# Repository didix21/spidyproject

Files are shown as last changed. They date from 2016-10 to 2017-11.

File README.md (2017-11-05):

# spidyproject


HitCount (http://hits.dwyl.io/didix21/spidyproject)
## About it
This repository contains all the necessary firmware to be implimented in Arduino's Spidy. Spidy is a six leg robot which is controlled with an Arduino and the spidyfirmware.  
Based on the robot: [Funny six feet + Myo](http://www.thingiverse.com/thing:1201161/#files)

# Characteristics
Description about the hardware and firmware used in spidy.
## Hardware
 * Plastic chasis.
 * Arduino.
 * 16 channels pwm controller.
 * 13 servo motors SG90.
 * Ultrasonic sensor.
 * MPU-6050 3 Axis Acceleration + Gyroscope / 6 Axis Attitude Module.
 * Raspberry Pi 2.0. (Optional for controll it manually)
 
 ## Firmware
 * spidyfirmware

## Things to do
**Hardware**
  * Implement the 16 channels pwm controller.
  
**Software**
  * Create new code for using the previous hardware.

## Contributors

- [Sxubach](https://github.com/sxubach)
  - He will create the communication between a PC, the Raspberry Pi 3.0 and Arduino MEGA. 

- [didix21](https://github.com/didix21)
  - Build the robot and the Hardware and implement it with a firmware that will allow to control the servos, obtain IMU's and Ultrasonics sensor data.

- [XMabbX](https://github.com/XMabbX)
  - Investigate about the algorithm which will allow the robot to learn to walk and prepare for the next step of the project.

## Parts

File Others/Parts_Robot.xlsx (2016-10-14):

Parts | Nº of them needed | Nº of Screws | Metrics | Length | Parts joined
LegP_0 | 6 | 2 | M3 | 15 mm M3 | LegP_1, LegP_2
LegP_1 | 6 | 2 | M3 | 15 mm M3 | LegP_0, LegP_4
LegP_2 | 6 | 1 | M3 | 15 mm M3 | LegP_0
LegP_3 | 13 | 1 | M3 | 8 mm M3 | 1xLegP_4, 1xLegP_5, 1xUSSensorFrame
LegP_4 | 6 | 4 | M3 | 3x 8 mm M3, 1x 15 mm M3 | LegP_1, LegP_3, LegP_5
LegP_5 | 6 | 3 | M3 | 3x 8 mm M3 | LegP_3, LegP_4
Base6servo | 1 | 4 | M3 | 4x 4 mm M3 | LegP_3, barillas, Arduino MEGA
bases6servoTop | 1 | 4 | M3 | 4x ? mm M3 (Especials) | barillas, USSSensorFrame
bases6servoTopHolder | 1 | 12 | M2, M3 | 4x 6 mm M2, 4x 6 mm M3, 4x ? mm M3 (Especials) | barillas, Rasprberrypi
Tornilleria | Mètrica | Longitud | Quantitat
Tornillo cabeza Cabeza cilindrico allen DIN 912 Inox A4 | M2 | 6 mm | 8
Tornillo cabeza Cabeza cilindrico allen DIN 912 Inox A4 | M3 | 4 mm | 12
Tornillo cabeza Cabeza cilindrico allen DIN 912 Inox A4 | M3 | 6 mm | 12
Tornillo cabeza Cabeza cilindrico allen DIN 912 Inox A4 | M3 | 8 mm | 59
Tornillo cabeza Cabeza cilindrico allen DIN 912 Inox A4 | M3 | 12 mm | 41
[985Z] TUERCA AUTOBLOCANTE DIN 985.8 ZINCADA | M3 |  | 124
[985Z] TUERCA AUTOBLOCANTE DIN 985.8 ZINCADA | M2 |  | 8

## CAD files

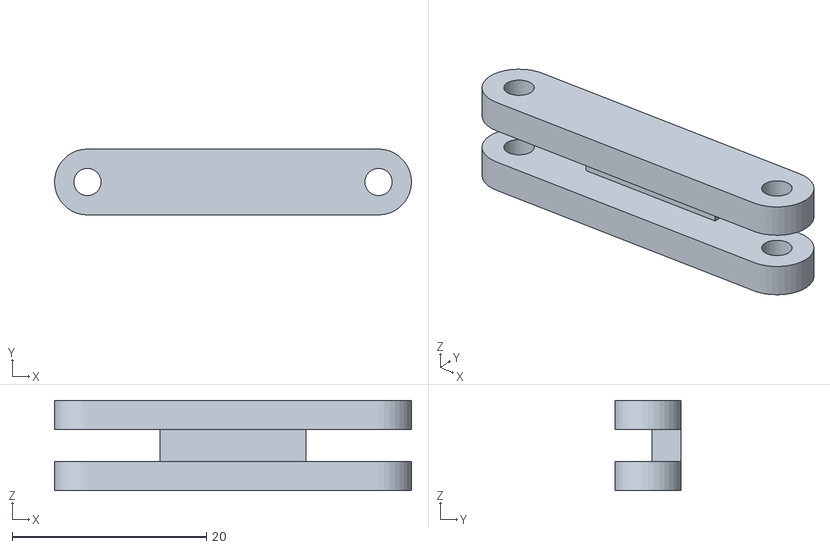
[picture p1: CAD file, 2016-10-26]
Others/Robot_STL/LegP_1.STL
36.8 x 6.80 x 9.30

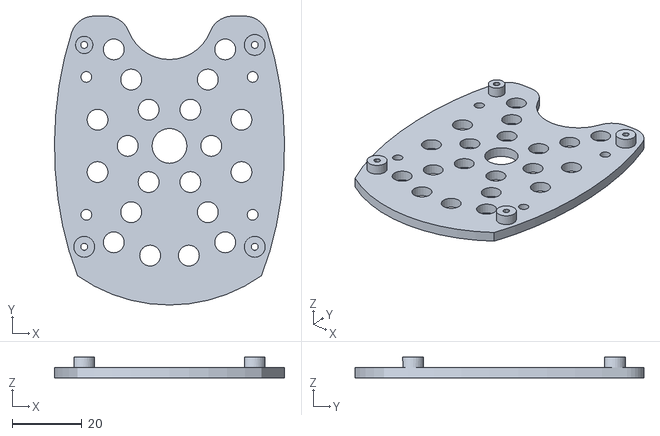
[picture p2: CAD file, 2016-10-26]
Others/Robot_STL/base6servoTopPIHolder.stl
66.1 x 83.0 x 6.00

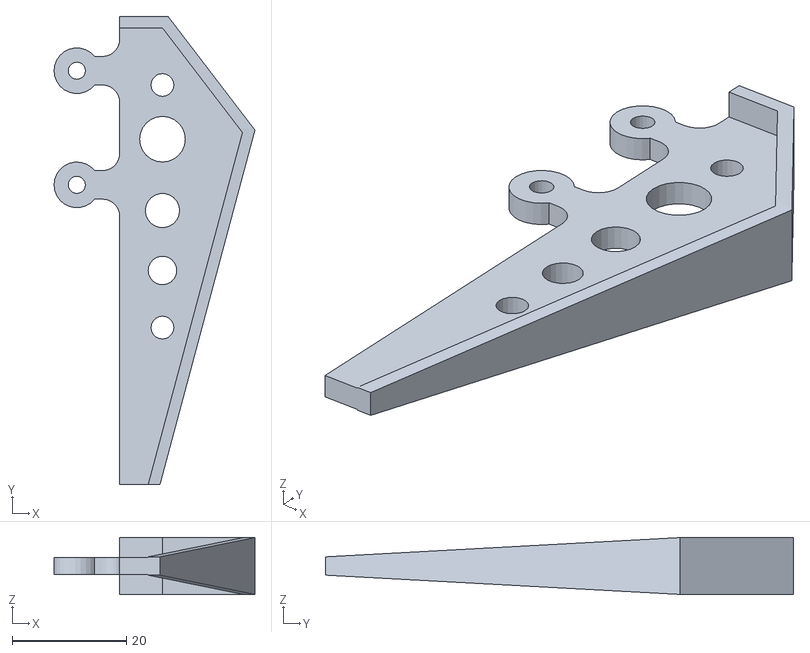
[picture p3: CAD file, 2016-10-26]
Others/Robot_STL/LegP_0.stl
35.2 x 82.0 x 10.0

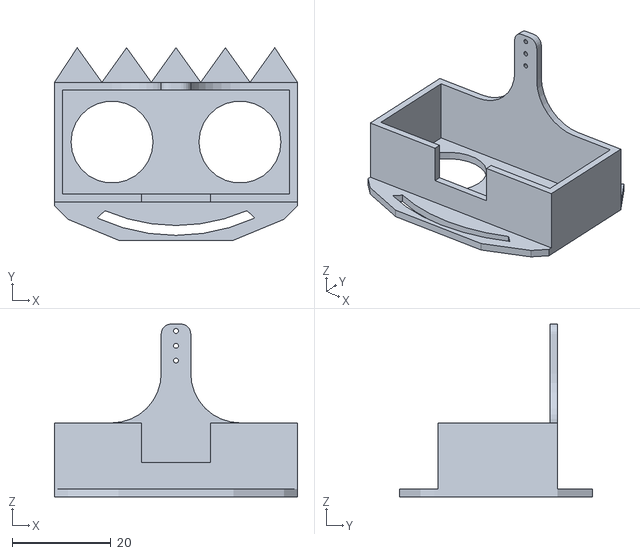
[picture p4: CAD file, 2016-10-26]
Others/Robot_STL/USSensorFrame.stl
49.2 x 39.0 x 35.0

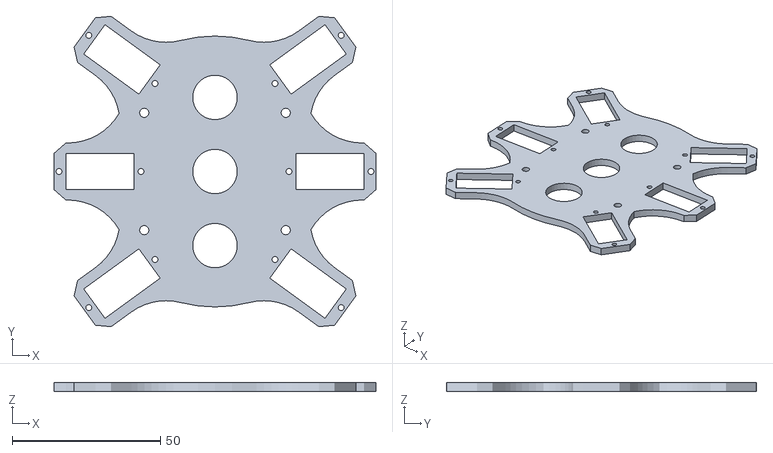
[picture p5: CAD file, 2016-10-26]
Others/Robot_STL/base6servo.stl
108.7 x 104.7 x 3.00

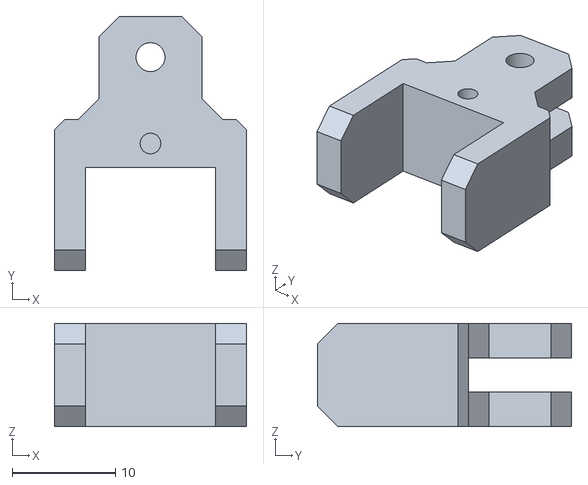
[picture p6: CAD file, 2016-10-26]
Others/Robot_STL/LegP_2.STL
18.6 x 24.6 x 10.0

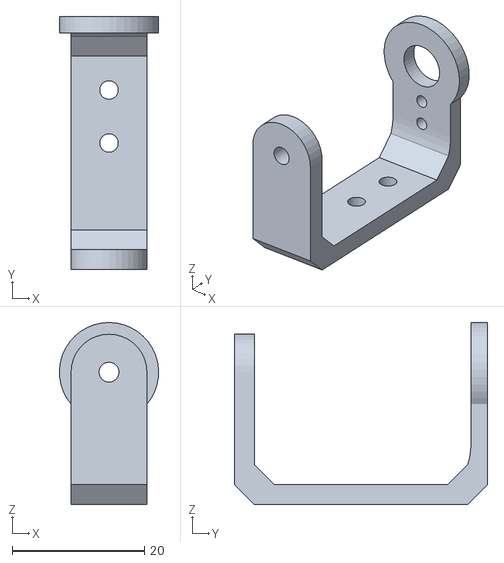
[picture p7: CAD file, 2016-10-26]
Others/Robot_STL/LegP_5.STL
15.0 x 38.2 x 27.5

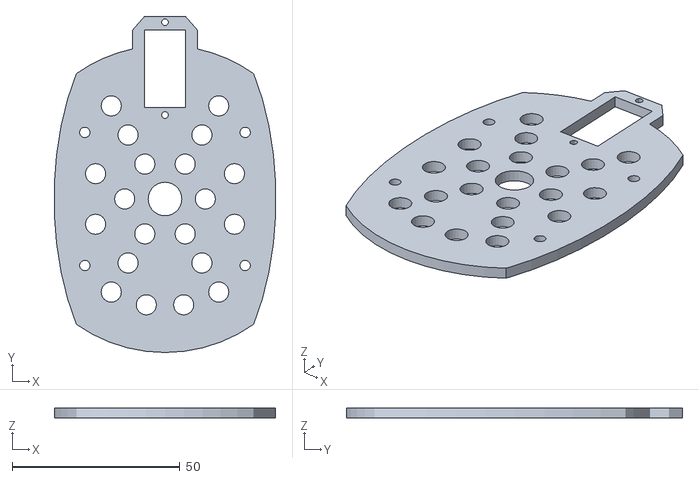
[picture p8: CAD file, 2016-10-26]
Others/Robot_STL/base6servoTop.stl
65.9 x 100.0 x 3.00

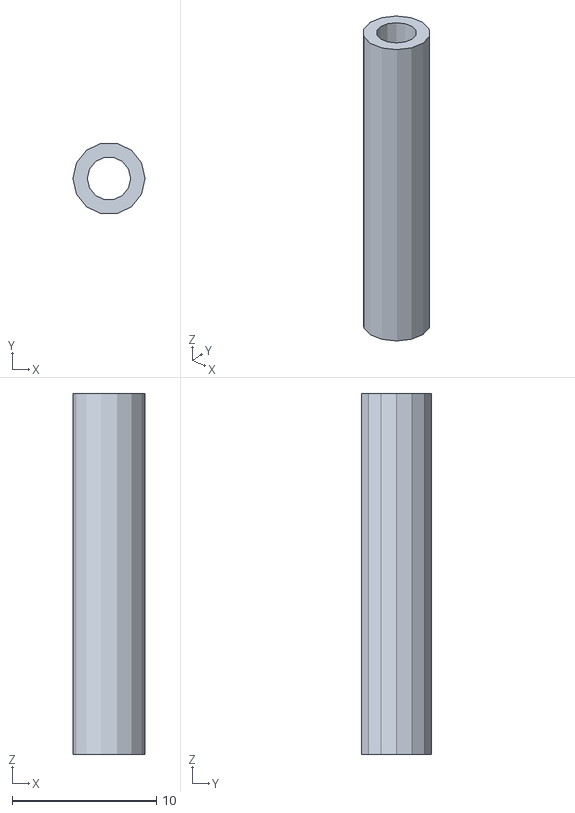
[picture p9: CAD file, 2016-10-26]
Others/Robot_STL/base6servoNo2Bar.stl
5.00 x 4.87 x 25.0

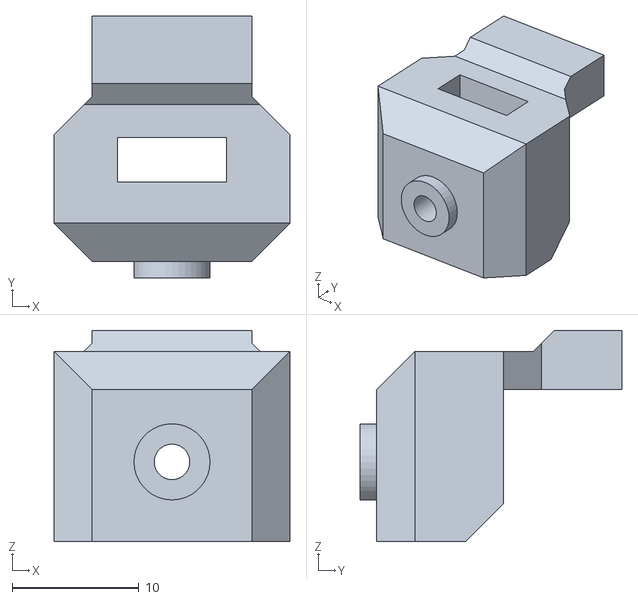
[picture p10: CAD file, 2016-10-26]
Others/Robot_STL/LegP_3.STL
18.6 x 20.7 x 16.6

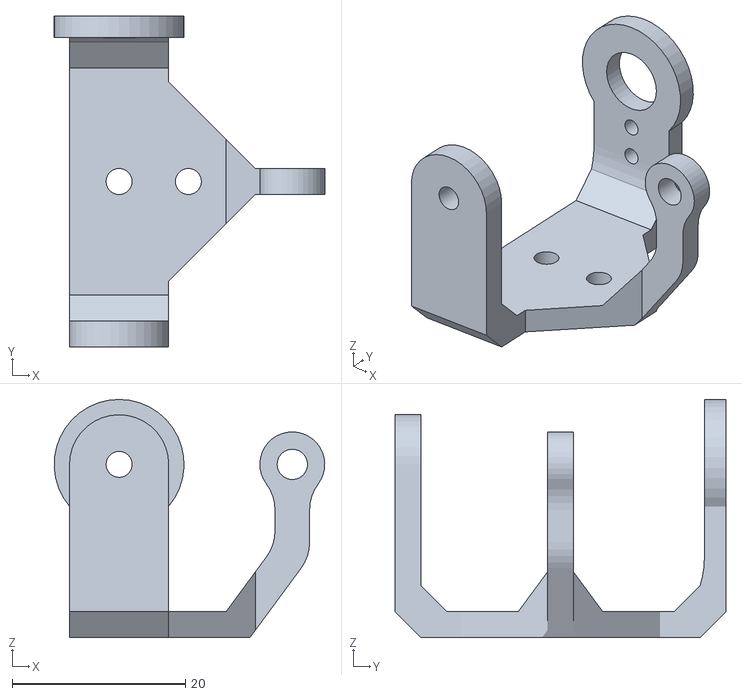
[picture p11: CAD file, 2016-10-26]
Others/Robot_STL/LegP_4.STL
31.2 x 38.2 x 27.5

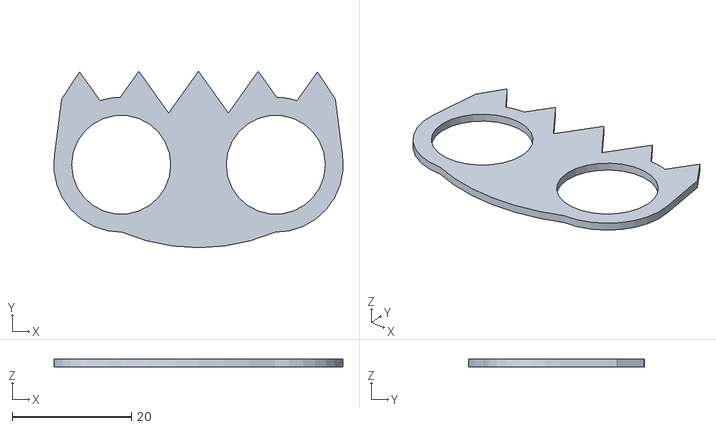
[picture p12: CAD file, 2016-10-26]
Others/Robot_STL/USSensorFrameG.stl
48.4 x 29.6 x 1.30

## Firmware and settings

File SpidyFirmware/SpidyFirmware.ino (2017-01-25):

/**
 * Spidyfirmware was created by Sergi Xavier Ubach and Dídac Coll. This firmware it is created in order to
 * use with the robot spidy. The refernces can be found in: 
 */



#include "main.h"

void setup() {
  // put your setup code here, to run once:
  MYSERIAL.begin(BAUDRATE);
  if(MYSERIAL.available()){
    MYSERIAL.println(ASTERISKS);
    MYSERIAL.println(SPIDY_FIRMWARE);
    MYSERIAL.println(ASTERISKS);
  }
  spidy.attachServos();
  spidy.setSpidyRest();
  init_comunication();
  ultrasound_setup();

}

void loop() {
  // put your main code here, to run repeatedly:
  #ifdef COMMANDLINE_CONTROL // Go to configuration and uncomment the #define COMMANDLINE_CONTROL
    
    commandLine();
    
  #else // Main Program to control with Raspberry PI
    
    update_duration_U();
    read_angles(legsAngle);
    
    #ifdef DEBUGGER // Debugger in order to print via serial the errors
    
      MYSERIAL.println(duration_U);
      MYSERIAL.print("pwm = [");
      MYSERIAL.print(legsAngle[0]);
      for (int i=1;i<12;i++){
        MYSERIAL.print(", ");
        MYSERIAL.print(legsAngle[i]);
      }
      MYSERIAL.println("]");
      
    #endif //DEBUGGER
        
    spidy.checkInsideMinMax(legsAngle); // Check if the angles send are inside the min max.
    spidy.refreshLegs(legsAngle);

    spidy.readLegsPosition(current_legsAngle);
    set_current_angles(current_legsAngle);

    #ifdef DEBUGGER  
    
      MYSERIAL.print("Distance_U = ");
      MYSERIAL.println(duration_U);
      MYSERIAL.print("pwm = [");
      MYSERIAL.print(legsAngle[0]);
      for (int i=1;i<12;i++){
        MYSERIAL.print(", ");
        MYSERIAL.print(legsAngle[i]);
      }
      MYSERIAL.println("]");    
    
    MYSERIAL.print("pwm = [");
    MYSERIAL.print(current_legsAngle[0]);
    for (int i=1;i<12;i++){
      MYSERIAL.print(", ");
      MYSERIAL.print(current_legsAngle[i]);
    }
    MYSERIAL.println("]");    
    
    #endif // DEBUGGER
    
    delay(50);
    
  #endif // COMMANDLINE_CONTROL
}

 #ifdef COMMANDLINE_CONTROL
 
   void serialEvent(){
      while(MYSERIAL.available()) {
        data=(char)MYSERIAL.read();    
        if (data != '\n'){
          syllable[i++]=data;   
        } else{
           MYSERIAL.println("Read Event Finished");
           comFinished = true; 
           x=i;
           i=0;
        }
      }
   }
   
  #endif

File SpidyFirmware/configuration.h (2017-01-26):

/**
 * This File contains all the numeret PINS needed and the servo configurations range
 */

#ifndef _CONFIGURATION_H_

  #define _CONFIGURATION_H_
  
 /**
  * L = Leg, Nº is the leg number.
  * S = Servo, Nº is the servo number: 1 is the servo near the paw and 2 is the base servo
  */

  /********************* SPIDY ********************
   *                                              *
   *                                              *
   *                     POWER                    *
   *                     -   +                    *
   *                     |   |                    *
   *       ________________________________       *
   *      |                                |      *
   * L6S2 | L6S1                      L5S1 | L5S2 *
   *      |                                |      *
   *      |                                |      *
   *      |                                |      *
   *      |                                |      *
   *      |                                |      *
   * L4S2 |  L4S1                     L3S1 | L3S2 *
   *      |                                |      *
   *      |                                |      *
   *      |                                |      *
   *      |                                |      *
   *      |                                |      *
   * L2S2 | L2S1                      L1S1 | L1S2 *
   *      |________________________________|      *
   *                    |     |                   *
   *                    |     |                   *
   *                    -------                   *
   *                      USB                     * 
   *                                              *
   ************************************************                      
   */
  // *********************************** SERVO PINS ***********************************
  #ifndef LNSN    
  
   #define L1S1_PIN 13   // Leg 1 Servo 1
   #define L1S2_PIN 12   // Leg 1 Servo 2
   #define L2S1_PIN 11   // Leg 2 Servo 1
   #define L2S2_PIN 10   // Leg 2 Servo 2
   #define L3S1_PIN 9   // Leg 3 Servo 1
   #define L3S2_PIN 8   // Leg 3 Servo 2
   #define L4S1_PIN 7   // Leg 4 Servo 1 
   #define L4S2_PIN 6  // Leg 4 Servo 2
   #define L5S1_PIN 5  // Leg 5 Servo 1
   #define L5S2_PIN 4  // Leg 5 Servo 2
   #define L6S1_PIN 3  // Leg 6 Servo 1
   #define L6S2_PIN 2  // Leg 6 Servo 2
  
  #endif // LNSN
  // ***********************************************************************************
  
  // Debugger mode 

 // #define DEBUGGER // If the define is not commented, the debugger mode is set
  
 // Serial Definition
 #ifndef MYSERESIAL
 
  #define MYSERIAL Serial // Usefull for MEGA we can change easily between Serial, Serial1, Serial2

  #ifndef BAUDRATE

    #define BAUDRATE 115200

  #endif

  ///#define COMMANDLINE_CONTROL // Uncomment this if you want to use command line to control spidy robot.
 
 #endif // MYSER

// *********************************** Range of each servo leg ***********************************

 #ifndef RANGE_OF_EACH_SERVO // 
  
  // Leg 1 
  #define L1S1_MIN 0  // In degrees
  #define L1S1_MAX 110 // In degrees
  #define L1S2_MIN 100 // In degrees
  #define L1S2_MAX 180 // In degrees
  // Leg 2
  #define L2S1_MIN 50 // In degrees
  #define L2S1_MAX 170 // In degrees
  #define L2S2_MIN 5 // In degrees
  #define L2S2_MAX 110 // In degrees
  // Leg 3
  #define L3S1_MIN 0 // In degrees
  #define L3S1_MAX 100 // In degrees
  #define L3S2_MIN 30 // In degrees
  #define L3S2_MAX 120 // In degrees
  // Leg 4
  #define L4S1_MIN 15 // In degrees
  #define L4S1_MAX 100 // In degrees
  #define L4S2_MIN 25 // In degrees
  #define L4S2_MAX 100 // In degrees
  // Leg 5
  #define L5S1_MIN 5 // In degrees
  #define L5S1_MAX 150 // In degrees
  #define L5S2_MIN 0 // In degrees
  #define L5S2_MAX 100 // In degrees
  // Leg 6
  #define L6S1_MIN 25 // In degrees
  #define L6S1_MAX 180 // In degrees
  #define L6S2_MIN 20 // In degrees
  #define L6S2_MAX 110 // In degrees

  // Centrate Base Paws
  #define L1S1_REST 50 //(L1S1_MAX - L1S1_MIN)/2
  #define L1S2_REST L1S2_MIN//(L1S2_MAX - L1S2_MIN)/2   //90
  #define L2S1_REST 110 //(L2S1_MAX - L2S1_MIN)/2
  #define L2S2_REST L2S2_MIN//(L2S2_MAX - L2S2_MIN)/2   //5
  
  #define L3S1_REST 50//(L3S1_MAX - L3S1_MIN)/2
  #define L3S2_REST L3S2_MIN//(L3S2_MAX - L3S2_MIN)/2   //30
  #define L4S1_REST 55//(L4S1_MAX - L4S1_MIN)/2
  #define L4S2_REST L4S2_MIN//(L4S2_MAX - L4S2_MIN)/2   //20
  
  #define L5S1_REST 60//(L5S1_MAX - L5S1_MIN)/2
  #define L5S2_REST L5S2_MIN//(L5S2_MAX - L5S2_MIN)/2   //0
  #define L6S1_REST 120   //(L6S1_MAX - L6S1_MIN)/2
  #define L6S2_REST L6S2_MIN//(L1S2_MAX - L6S2_MIN)/2   //60
                     
  #define RANGE_OF_EACH_SERVO

 #endif // RANGE_OF_EACH_SERVO

// **************************************************************************************************

#endif // _CONFIGURATION_H_

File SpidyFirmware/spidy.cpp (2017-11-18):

#include "spidy.h"
  
  /** 
   *  Constructor
   */
  Spidy::Spidy() {
       // Nothing
  }

  void Spidy::attachServos() {
       // Initialize Servo Motors
    l1s1.attach(L1S1_PIN);
    l1s2.attach(L1S2_PIN);
    l2s1.attach(L2S1_PIN);
    l2s2.attach(L2S2_PIN);
    l3s1.attach(L3S1_PIN);
    l3s2.attach(L3S2_PIN);
    l4s1.attach(L4S1_PIN);
    l4s2.attach(L4S2_PIN);
    l5s1.attach(L5S1_PIN);
    l5s2.attach(L5S2_PIN);
    l6s1.attach(L6S1_PIN);
    l6s2.attach(L6S2_PIN); 
    
  }

  /** 
   * Sent all the servos to rest  
   */
  void Spidy::setSpidyRest() {
    
    l1s1.write(L1S1_REST);
    l1s2.write(L1S2_REST);
    l2s1.write(L2S1_REST);
    l2s2.write(L2S2_REST);
    l3s1.write(L3S1_REST);
    l3s2.write(L3S2_REST);
    l4s1.write(L4S1_REST);
    l4s2.write(L4S2_REST);
    l5s1.write(L5S1_REST);
    l5s2.write(L5S2_REST);
    l6s1.write(L6S1_REST);
    l6s2.write(L6S2_REST);
    
   }

   /** 
    * To rise Spidy 
    */
   void Spidy::setSpidyUp() {
    
    l1s2.write(L1S2_MAX);
    l2s2.write(L2S2_MAX);
    l3s2.write(L3S2_MAX);
    l4s2.write(L4S2_MAX);
    l5s2.write(L5S2_MAX);
    l6s2.write(L6S2_MAX);
    
   }

  /** 
   * Set down Spidy
   */
   void Spidy::setSpidyDown() {
    
    l1s2.write(L1S2_MIN);
    l2s2.write(L2S2_MIN);
    l3s2.write(L3S2_MIN);
    l4s2.write(L4S2_MIN);
    l5s2.write(L5S2_MIN);
    l6s2.write(L6S2_MIN);
  
   }

  /**
   * This function is in charge of refresh all the servo legs.
   * Possible some time delays will be implemented in futur to 
   * avoid high inductances and Arduino Saturation.
   */
   void Spidy::refreshLegs(uint8_t *legsAngle) {

    // Actualize legs position
    l1s1.write(legsAngle[0]);
    l1s2.write(legsAngle[1]);
    l2s1.write(legsAngle[2]);
    l2s2.write(legsAngle[3]);
    l3s1.write(legsAngle[4]);
    l3s2.write(legsAngle[5]);
    l4s1.write(legsAngle[6]);
    l4s2.write(legsAngle[7]);
    l5s1.write(legsAngle[8]);
    l5s2.write(legsAngle[9]);
    l6s1.write(legsAngle[10]);
    l6s2.write(legsAngle[11]);
    
   }

  /**
   * This function read all the actual servo values
   */
   void Spidy::readLegsPosition(uint8_t *legsPosition) {
    
    //uint8_t legsPosition[12]; // Twelve Servo Motors
    
    // Read actual legs position
    legsPosition[0] = l1s1.read();
    legsPosition[1] = l1s2.read();
    legsPosition[2] = l2s1.read();
    legsPosition[3] = l2s2.read();
    legsPosition[4] = l3s1.read();
    legsPosition[5] = l3s2.read();
    legsPosition[6] = l4s1.read();
    legsPosition[7] = l4s2.read();
    legsPosition[8] = l5s1.read();
    legsPosition[9] = l5s2.read();
    legsPosition[10] = l6s1.read();
    legsPosition[11] = l6s2.read();

   
   }
   
   /**
    * CheckPostion: checks if all the servo have reached the goal values.
    */
   bool *Spidy::checkPosition(uint8_t *legsAngle, uint8_t *legsPosition) {
    
    bool *checkArray = new bool[12]; // This array will be used to know if all the servos has achieved the position
    
    // Check if servos has achieved the position desired
    for(int i = 0; i < 11; i++) {
      // (legsAngle[i] - 10) <= legsPosition[i] <= (legsAngle[i] + 10)
      if((legsPosition[i] >= (legsAngle[i] - 10)) && (legsPosition[i] <= (legsAngle[i] + 10))) { 
        checkArray[i] = true;
      } 
      else {
        checkArray[i] = false;
      }
    }

    return checkArray; 
   }
   
   /**
    * checkInsideMinMax: check if each servo angle received is inside min max range.
    * This function avoids force the different servos.
    */
   void Spidy::checkInsideMinMax(uint8_t *legsAngle) {
    
    int i;
    for(i = 0; i < 11; i++) {
      if(legsAngle[i] < minPos[i]) legsAngle[i] = minPos[i];
      else if(legsAngle[i] > maxPos[i]) legsAngle[i] = maxPos[i];
    }   
   }
   

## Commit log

2016-10-02 uploading a first version of the code for i2c comunication from the aruino and controll of the servos and ultrasound
2016-10-03 Initial concept of the server for the topics related to arduino
2016-10-14 Menor changes in spidyfirmware
    [configuration.h]
2016-10-26 Arduino and STL files added
    [LegP_0.stl, LegP_1.STL, LegP_2.STL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]
2016-10-27 first merge of comunication code with spider control
    [configuration.h]
2016-11-11 no changes
    [configuration.h]
2016-11-17 Change constructor
    [configuration.h]
2016-11-17 adding gyro reading for the MPU6050
2016-11-17 starting to work in ros node with service for pwm
2016-11-18 changes in prints
2016-11-18 refreshMode added
    [configuration.h]
2016-11-24 This Works Perfectly Well
    [configuration.h]
2017-01-03 Merge remote-tracking branch 'refs/remotes/origin/master' into learning_algorithm
    # Conflicts:
    # Algorithm/CB project/Algorithm/Algorithm.cbp
    # Algorithm/CB project/Algorithm/main.cpp
    # Algorithm/CB project/Algorithm/var.h
    # Algorithm/CB project/NEAT/NEAT.cbp
    # Algorithm/CB project/NEAT/NEAT.cpp
    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
2017-01-03 Uploaded crab_project folder, Now Works
    [Tibia_foot_new.STL, coxa_l.STL, coxa_r.STL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]
2017-01-03 crab_project inside ROS
    [Tibia_foot_new.STL, coxa_l.STL, coxa_r.STL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]
2017-01-04 socket working i2c minor issues
2017-01-04 socket fully operational
2017-01-04 Communication working from action node to arduino
2017-01-09 Added function that checks that angles are inside min max
    [configuration.h]
2017-01-09 fixing arduino issues
    [configuration.h]
2017-01-09 Debugger Implemented
    [configuration.h]
2017-01-12 passing current position of servos
2017-01-21 Added Some comments in configuration.h file
    [configuration.h]
2017-01-21 No important changes
    [configuration.h]
2017-01-23 Changes in min max angles
    [configuration.h]
2017-01-23 Added Comments
    [configuration.h]
2017-01-24 updated limit min and max
    [configuration.h]
2017-01-25 Deleted unnecessary files
    [LegP_0.stl, LegP_1.STL, LegP_2.STL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]
2017-01-25 Deleted Arduino_programs
    [configuration.h]
2017-01-26 gyro and acc initialized
    [configuration.h]
2017-11-18 Errors due to checkPosition function, solved
    [spidy.cpp]
